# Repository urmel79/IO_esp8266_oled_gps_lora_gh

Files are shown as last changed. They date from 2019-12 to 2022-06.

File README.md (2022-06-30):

# LoRa and LoRaWAN testing bench with GPS tracking

Last changed on June 30, 2022.

## Table of contents

<!--
@HINT:
auto-generate the TOC with the command line tool 'gh-md-toc' (https://github.com/ekalinin/github-markdown-toc) with following syntax:
$ cat README.md | ./tools/github-markdown-toc/gh-md-toc - > toc.md
-->

* [Introduction](#introduction)
  * [Aim of the project](#aim-of-the-project)
  * [Requirements to the testing bench](#requirements-to-the-testing-bench)
* [A brief overview of LoRa topologies](#a-brief-overview-of-lora-topologies)
* [LoRa or LoRaWAN? - The difference is 1 GPIO pin of the ESP](#lora-or-lorawan---the-difference-is-1-gpio-pin-of-the-esp)
* [Node-RED Flows](#node-red-flows)
* [Display GPS tracks on OSM worldmap](#display-gps-tracks-on-osm-worldmap)
* [Storing the transmitted data: SQLite database layout](#storing-the-transmitted-data-sqlite-database-layout)
* [Visual impressions of my experimental breadboard setup](#visual-impressions-of-my-experimental-breadboard-setup)
* [Bill of materials (BOM)](#bill-of-materials-bom)
* [Breadboard layout and schematics (version with ESP8266)](#breadboard-layout-and-schematics-version-with-esp8266)
* [Breadboard layout and schematics (version with ESP32)](#breadboard-layout-and-schematics-version-with-esp32)
* [Troubleshooting](#troubleshooting)
  * [Writing serial output with timestamps to a logfile](#writing-serial-output-with-timestamps-to-a-logfile)
    * [Method 1: Use minicom](#method-1-use-minicom)
    * [Method 2: Use command line tools](#method-2-use-command-line-tools)
  * [I²C: fighting strange pixel errors on OLED display](#ic-fighting-strange-pixel-errors-on-oled-display)
    * [Observation](#observation)
    * [Thesis 1: EMC issues with the LoRa radio module](#thesis-1-emc-issues-with-the-lora-radio-module)
    * [Thesis 2: Power supply of the MCU is to weak](#thesis-2-power-supply-of-the-mcu-is-to-weak)
    * [Thesis 3: I²C signals at SDA and SCL line are disturbed](#thesis-3-ic-signals-at-sda-and-scl-line-are-disturbed)
* [License](#license)

# Introduction

## Aim of the project

The aim of this project is to build a test environment based on ESP8266 or ESP32 for [LoRa](https://en.wikipedia.org/wiki/LoRa) and LoRaWAN as [LPWAN](https://en.wikipedia.org/wiki/LPWAN) long-range radio network.

## Requirements to the testing bench

For this purpose, two identical test modules were each equipped with a LoRa transceiver, a GPS module and an OLED display for displaying the current data.

Both test modules were initially prototypically built on breadboards. Power is supplied via the microUSB port of the ESP8266 NodeMCU (respectively NodeMCU ESP-32S) and optionally connected to the USB port of the development computer. This allows debugging via the serial interface and the serial monitor at the same time.

Alternatively, a LiPo power bank can also be used for both test modules, making them mobile for upcoming range tests.

At the moment, watertight food storage boxes are used as provisional and outdoor-suitable housings.

Firmware updates can be submitted via USB-to-serial interface or by using the *Over-The-Air (OTA)* update functionality to take advantage of maximum mobility :) In my opinion this is an essential feature for IoT applications! For an introduction to this technique start here: [Over-the-air programming](https://en.wikipedia.org/wiki/Over-the-air_programming) or there: [ESP8266 OTA Updates with Arduino IDE | Over the Air](https://randomnerdtutorials.com/esp8266-ota-updates-with-arduino-ide-over-the-air/).

GPS coordinates are transferred via MQTT to a Raspberry-based Node-RED-Server. On this server there is a dedicated flow what cares for
- the displaying on the OpenStreetMap widget (install *'node-red-contrib-web-worldmap'* package) and
- the storage of the GPS coordinates (smoothed by floating average) in a SQLite database (install *'node-red-node-sqlite'* package).

# A brief overview of LoRa topologies

LoRa is usable in an **Point to Point communication** like this:

<!-- @TODO: insert image of LoRa p2p -->
(image will follow soon)

Furthermore, it can be used in an full blown LoRa network on the basis of **LoRaWAN** like this:

<!-- @TODO: insert image of LoRaWAN network -->
(image will follow soon)

# LoRa or LoRaWAN? - The difference is 1 GPIO pin of the ESP

For the application of a [TTN](https://www.thethingsnetwork.org/docs/) based LoRaWAN network 1(!) additional GPIO pin of the ESP mcu to the LoRa transceiver module is required. Unfortunately, this pin of the ESP8266 is not available because all others are already occupied by the other peripherals and communication channels (e. g. *UART* to the gps sensor, *I2C* to the OLED display and *SPI* to the LoRa transceiver module itself).

Because of this dilemma the whole project had to be migrated for the use of ESP32 with its significantly more GPIO pins. It was a hard piece of work since there are many differences in the Arduino API especially in the wifi handling. So there are many `#defines` in the source for choosing the right mcu platform and software modules.

# Node-RED Flows

Here you can see the Node-RED Flow for displaying the GPS coordinates on the OpenStreetMap and for storaging in an SQLite database for 2 ESP nodes:

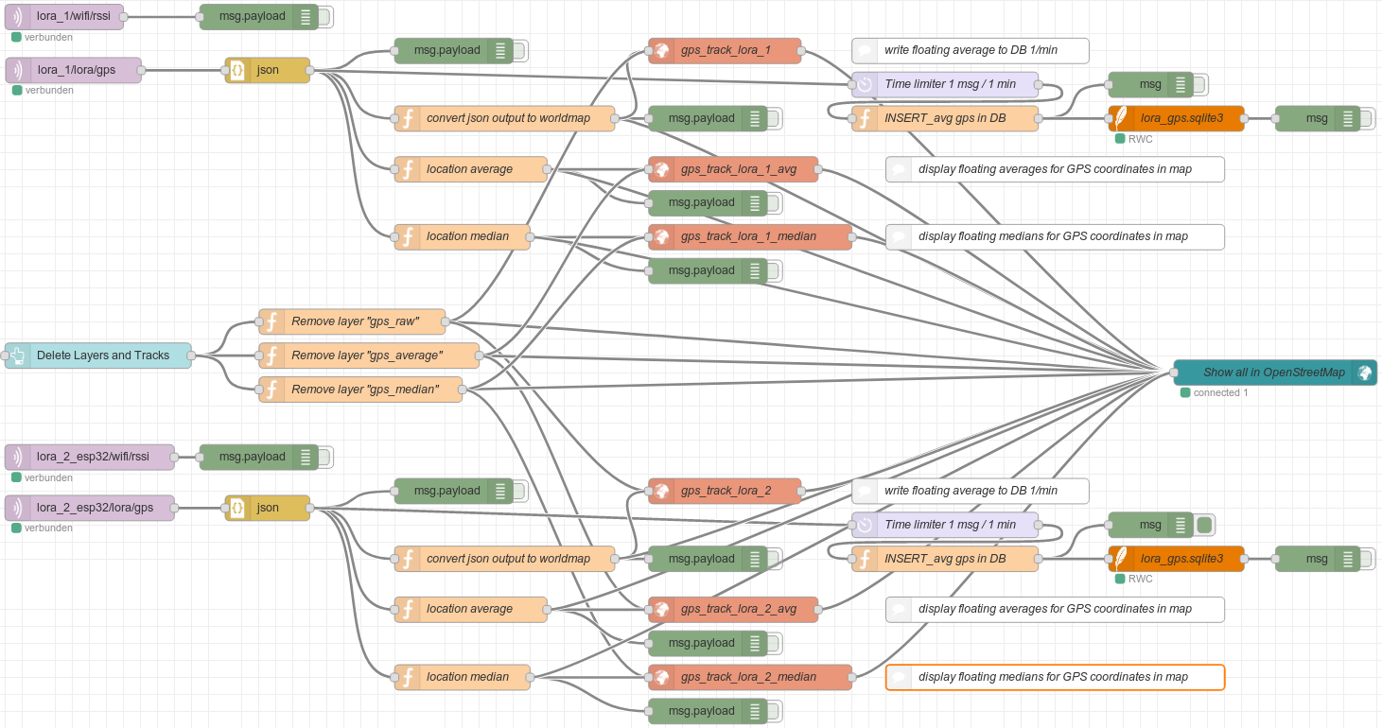
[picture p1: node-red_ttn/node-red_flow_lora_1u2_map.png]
Node-RED Flow LoRa Nodes 1 and 2 and GPS mapping


There is my Node-RED Flow ready to import it to your own Node-RED installation [lora_1u2_map.json](./node-red_ttn/lora_1u2_map.json). To use it, you have to additionally install following Node-RED packages:

- `node-red-dashboard`
- `node-red-contrib-web-worldmap`
- `node-red-node-sqlite`

# Display GPS tracks on OSM worldmap

The experimental breadboard setup (including the gps sensor) is located on the outside windowsill of my office with a view to the southeast. This is a screenshot of the OSM worldmap and the gps tracks recorded over some time:

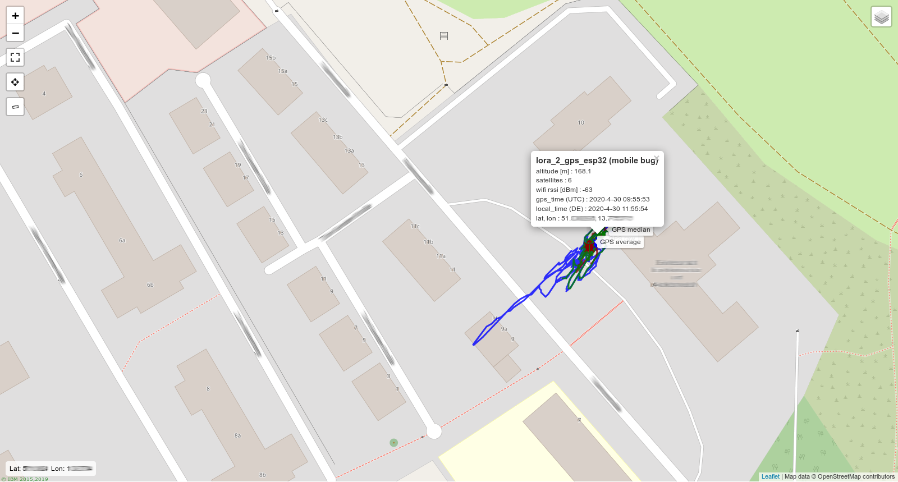
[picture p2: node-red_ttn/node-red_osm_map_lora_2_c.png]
OSM worldmap with LoRa 1


The colors of the gps tracks have the following meaning:

- blue: *raw* positioning data from gps sensor
- red: smoothed data by *running average*
- green: smoothed data by *running median*

# Storing the transmitted data: SQLite database layout

Here is a screenshot of *phpLiteAdmin* to show my SQLite database layout for storing the GPS coordinates:

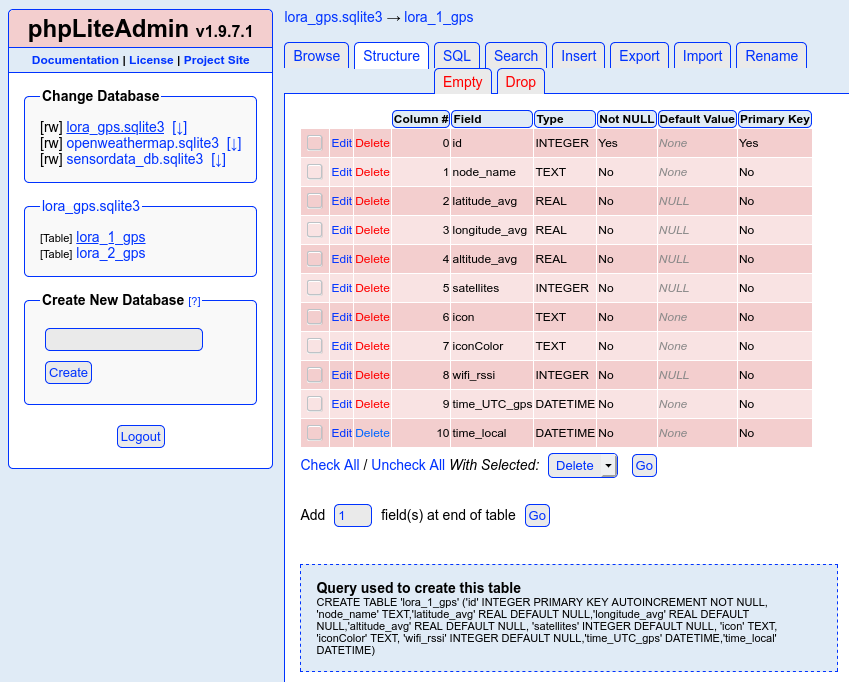
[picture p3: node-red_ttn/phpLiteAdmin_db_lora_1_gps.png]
SQLite database layout


# Visual impressions of my experimental breadboard setup

Here you can see one of two test modules build on breadboard:

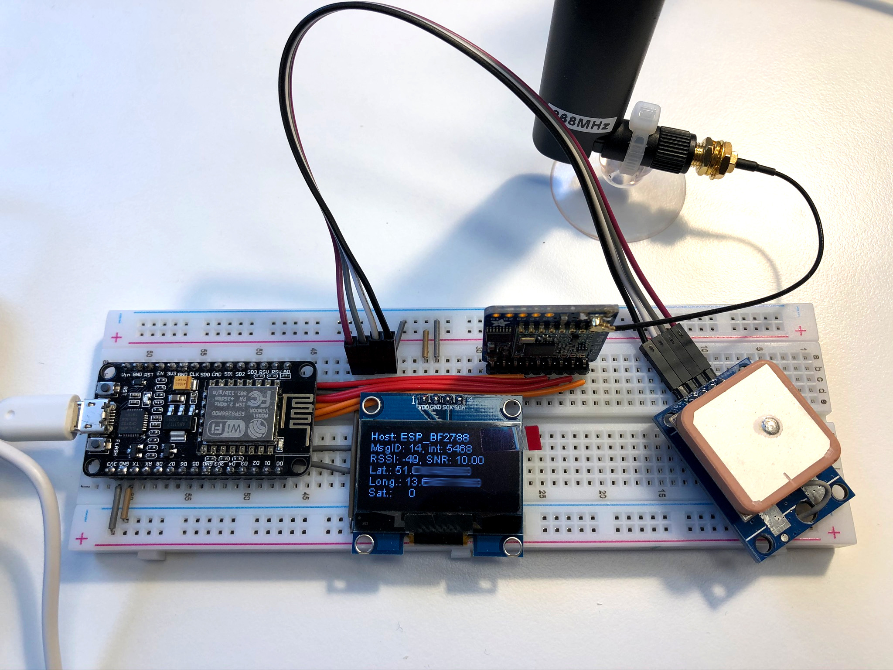
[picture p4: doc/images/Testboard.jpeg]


In this picture you can see the other test module on top of the provisional and outdoor-suitable housing (watertight food storage box):

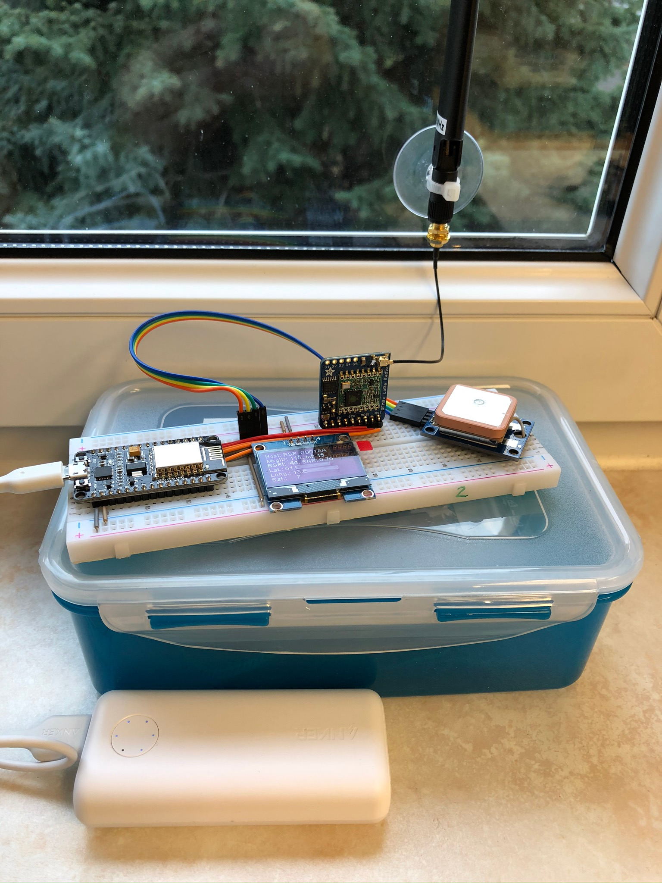
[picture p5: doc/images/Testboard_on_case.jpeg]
Breadboard Layout and case


# Bill of materials (BOM)

Following parts I have used in this project (every component you will need twice of course):

- **NodeMCU v2 (ESP8266)** or **NodeMCU ESP-32S**
- OLED I2C display, 128 x 64 Pixel, 1.3 Zoll (SSH1106 chip)
- GPS module u-blox Neo-6M (GY-GPS6MV2 chip)
- LoRa transceiver Adafruit RFM9x LoRa Radio (RFM95W chip, 868 MHz)
- LoRa antenna (868 MHz), 3 dBi omnidirectional
- u.FL/IPEX to SMA connector (so called 'pigtail')
- USB cable with micro USB plug
- breadboard full+ (830 holes)
- wire jumpers
- LiPo battery pack

# Breadboard layout and schematics (version with ESP8266)

With *Fritzing* (https://fritzing.org) I have created following breadboard layout:

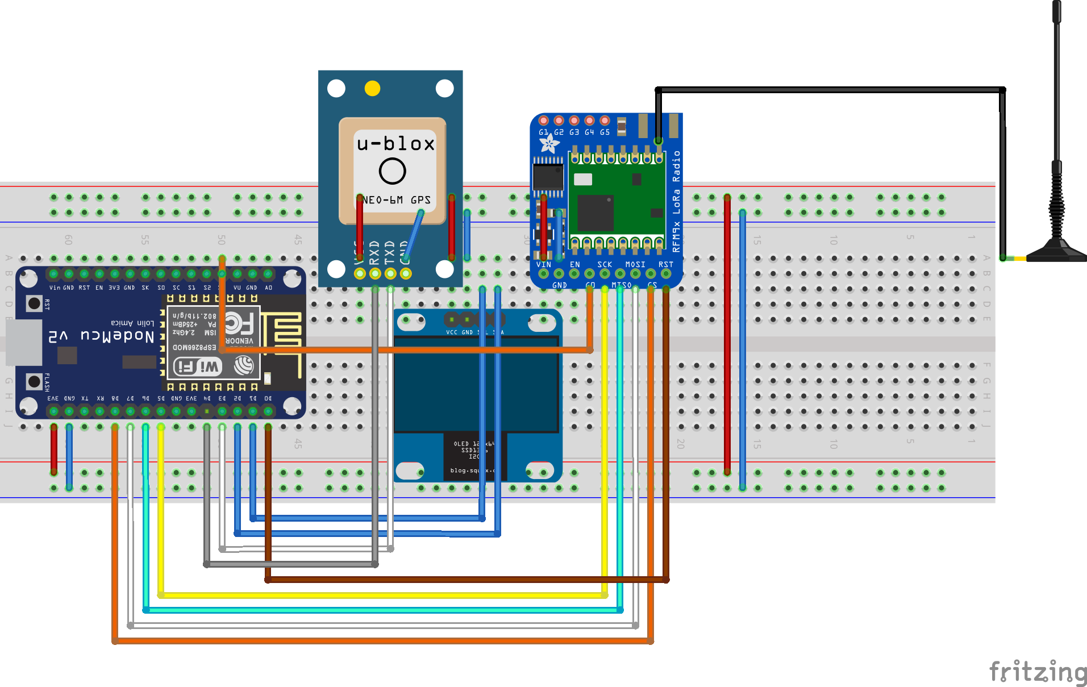
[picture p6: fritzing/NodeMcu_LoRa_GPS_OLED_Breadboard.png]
Breadboard Layout


The schematics looks like this:

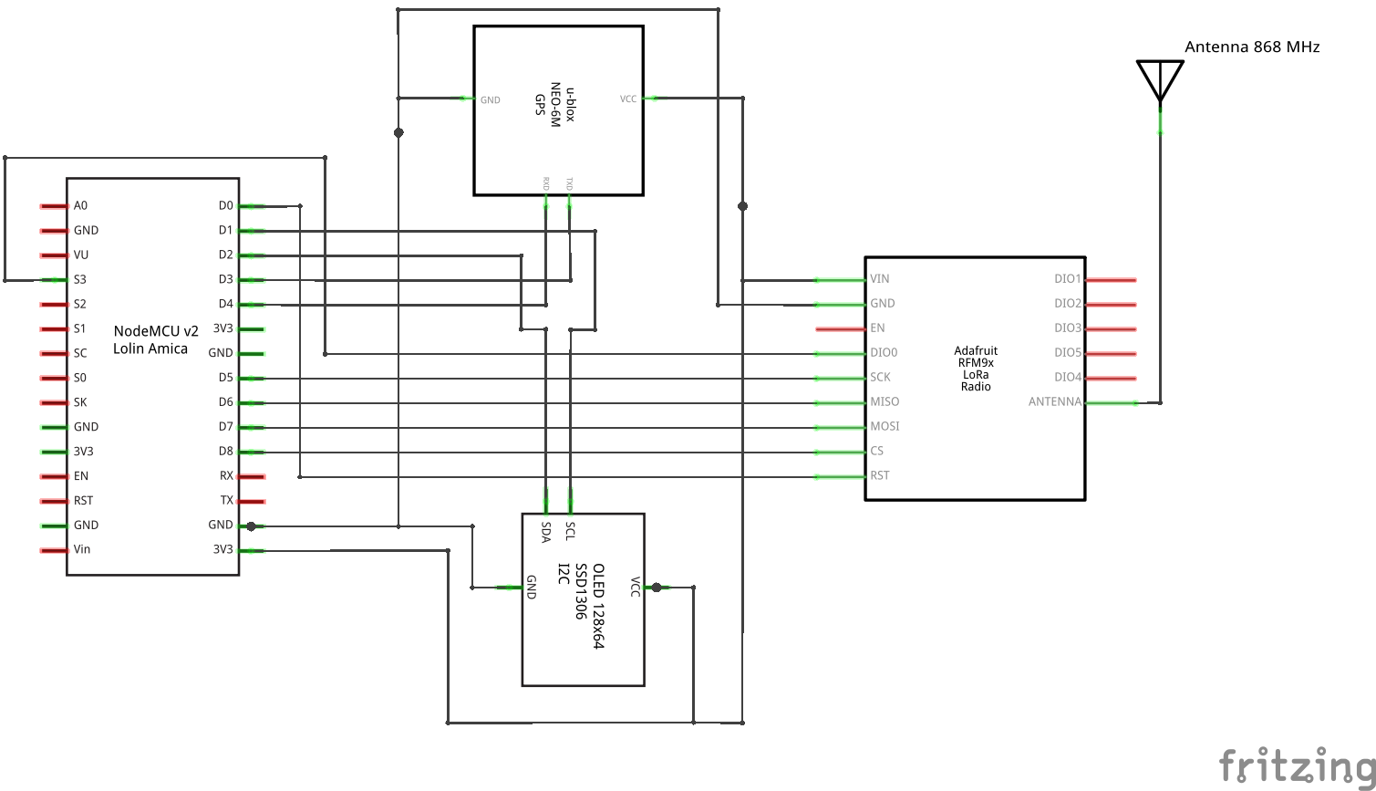
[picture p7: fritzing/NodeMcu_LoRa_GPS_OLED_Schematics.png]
Schematics


# Breadboard layout and schematics (version with ESP32)

With *Fritzing* (https://fritzing.org) I have created following breadboard layout:

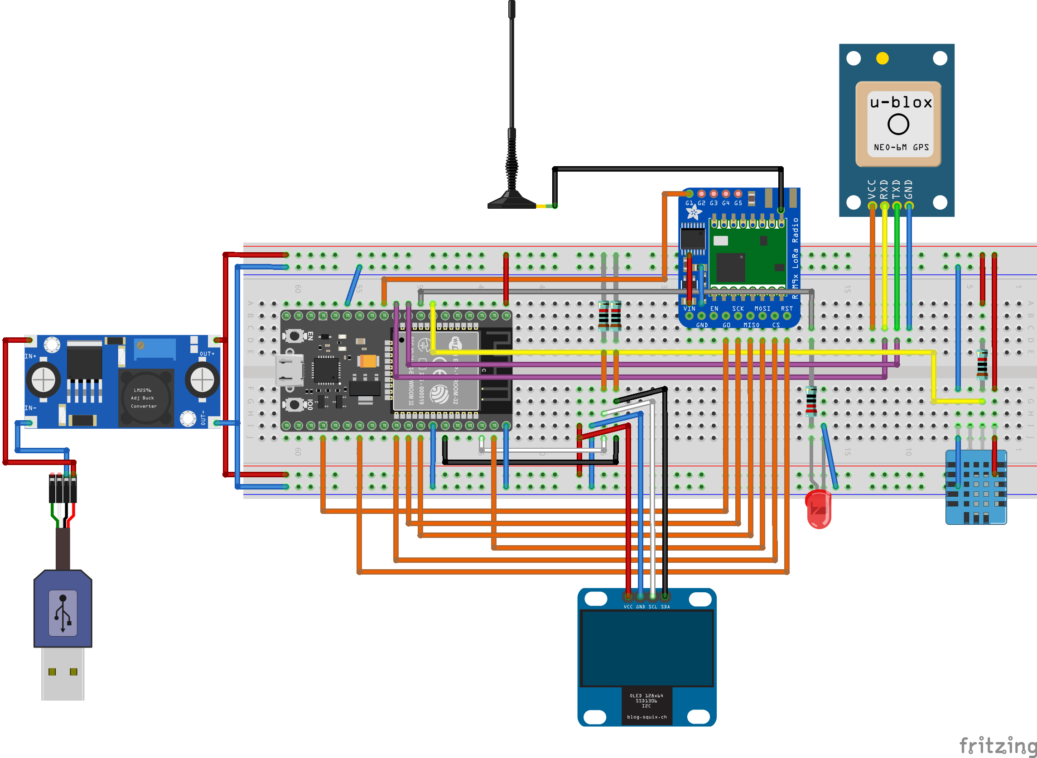
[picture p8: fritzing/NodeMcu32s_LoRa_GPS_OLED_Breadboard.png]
Breadboard Layout


The schematics looks like this:

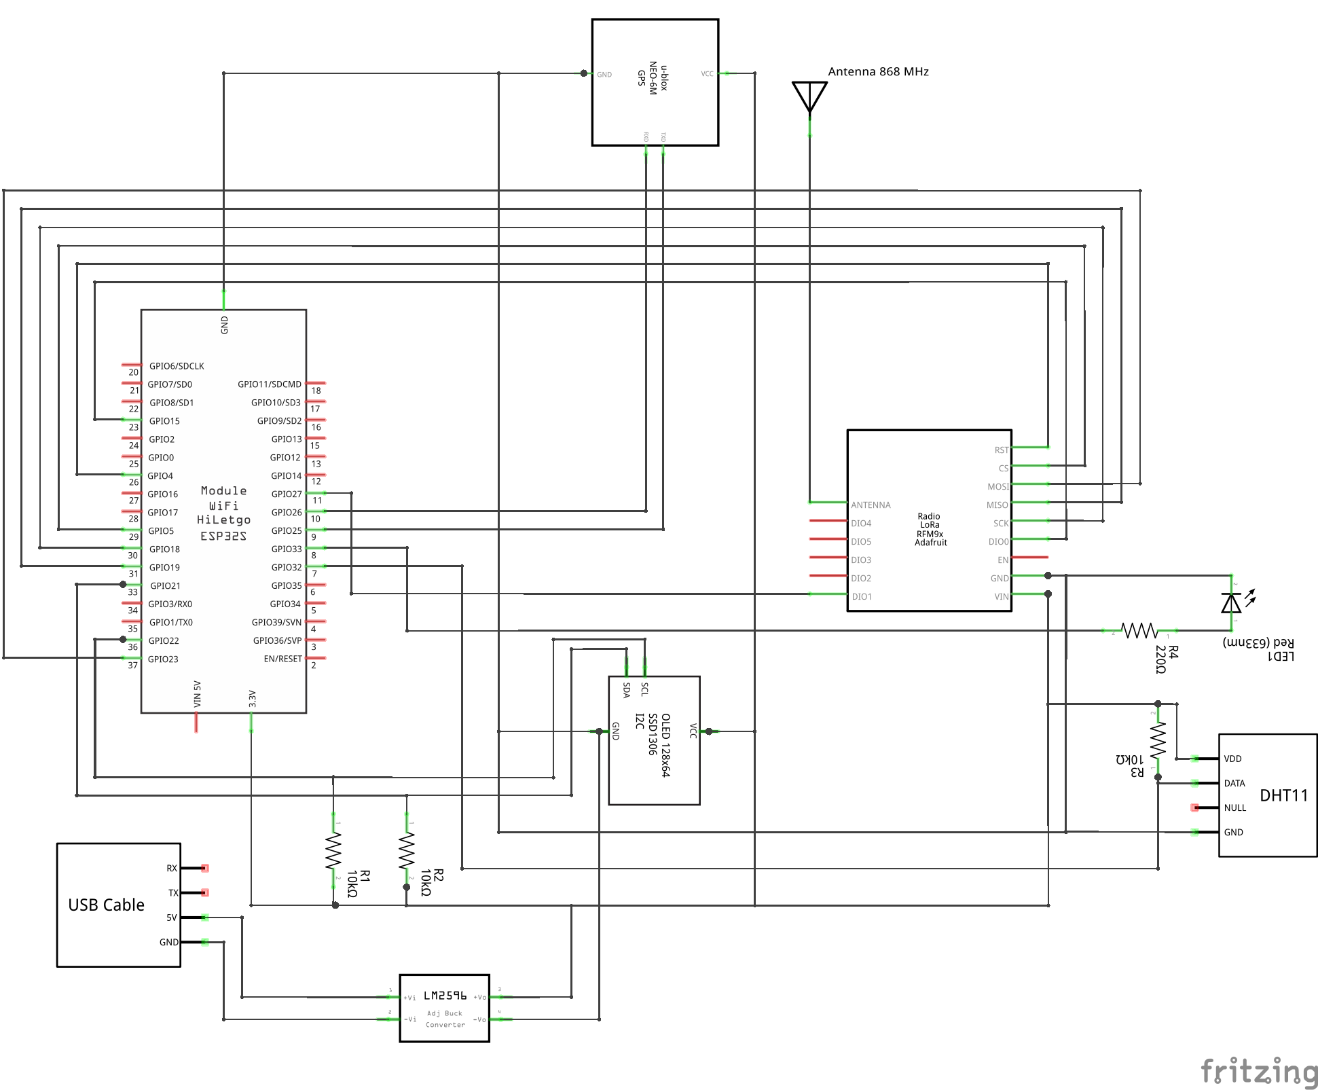
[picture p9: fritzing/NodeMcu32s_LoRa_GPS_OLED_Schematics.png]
Schematics


<!--## Software libraries and documentation

Go to the source code: I have supplied it with many comments for explanation.-->

# Troubleshooting

In this section I will describe some typical hardware or software problems that I have struggled with for several days.

(to be continued)

## Writing serial output with timestamps to a logfile

Connect the ESP8266 / ESP32 via a microUSB cable directly to a Linux computer or a Raspberry Pi.

### Method 1: Use `minicom`

Start `minicom` and configure the serial connection via `C-a o`. Especially the path to the serial device (e. g. `/dev/ttyUSB0`), the correct baud rate (115200 baud) and the stop and parity bits (8N1) have to be set.

Activate timestamps via `C-a n`. Do that several times and cycle through the timestamps modes: 'no timestamps', 'simple timestamps' and 'advanced timestamps' (with milliseconds). I use the latter mode, because the serial output with 115200 baud is really fast. See the screenshot below.

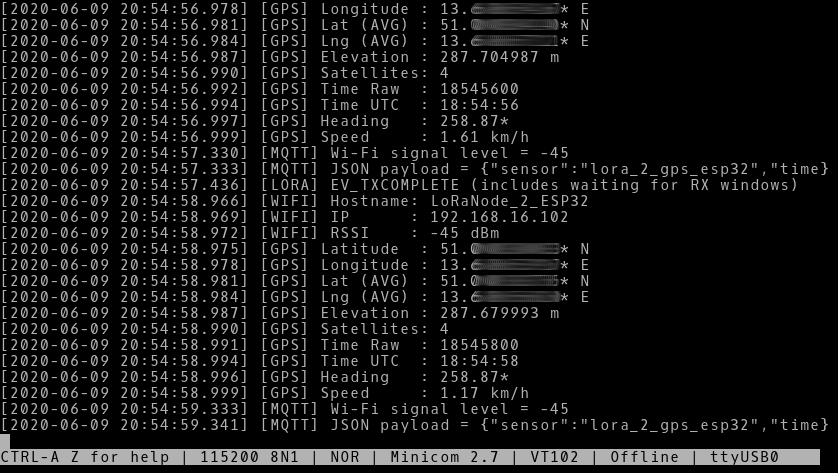
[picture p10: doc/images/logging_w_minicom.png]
Screenshot of minicom with activated timestamps


Activate the logging function in `minicom` via `C-a l`. In the dialog box you have to set your desired file name.

### Method 2: Use command line tools

Build a pipeline with several command line tools. For getting timestamps I use the `ts` command - the package `moreutils` has to be installed first (`# apt install moreutils`).

**Prerequisite:** The serial device has to be opened first with the correct settings via another serial tool, like `minicom`.

This is the complete command pipeline:

`$ ts '[%Y-%m-%d %H:%M:%.S]' < /dev/ttyUSB0 | tee -a $(date +%Y-%m-%d)_esp32.log`

Here is the screenshot showing this method:

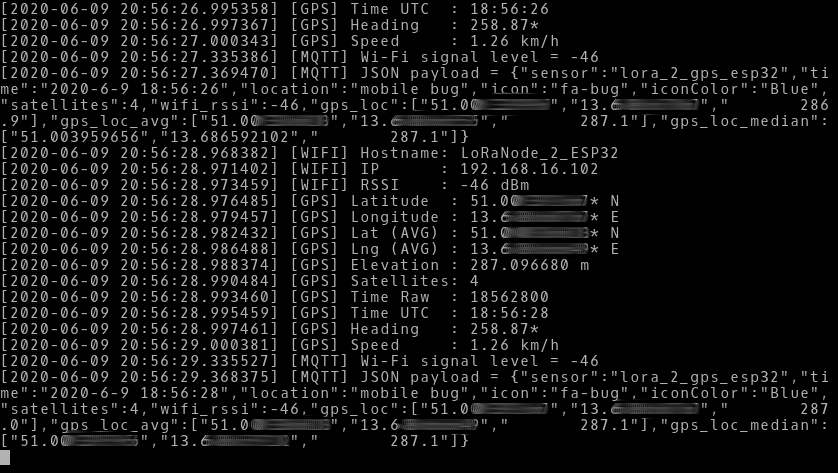
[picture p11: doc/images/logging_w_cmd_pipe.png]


The advantage of piping the `tee` command is, that you can watch the serial output while the logging is done in the background. The option `-a` means, that the given file is appended and not overwritten.

## I²C: fighting strange pixel errors on OLED display

### Observation

After some time there are random pixel errors on the OLED display. It can also happen that the display turns almost completely white and nothing is readable anymore.

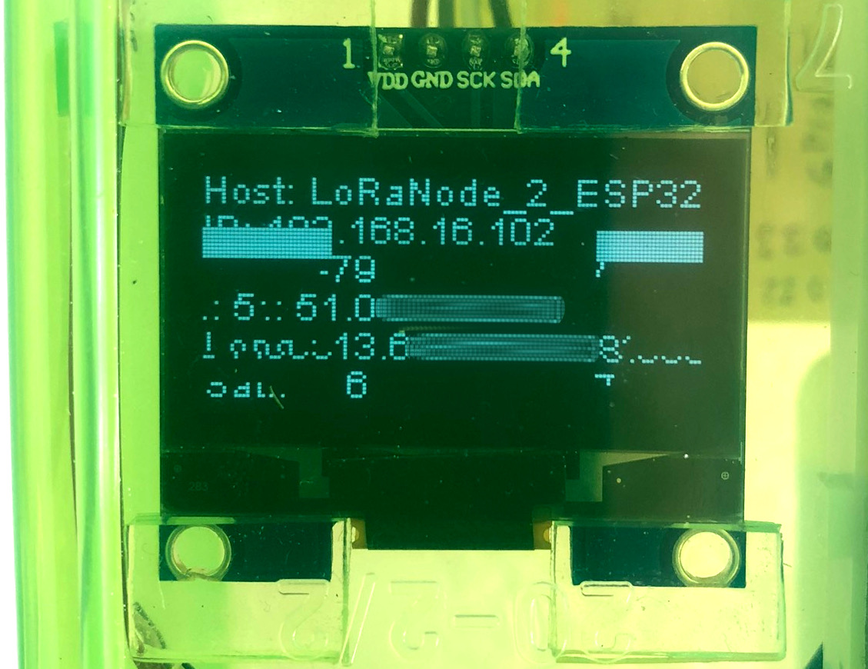
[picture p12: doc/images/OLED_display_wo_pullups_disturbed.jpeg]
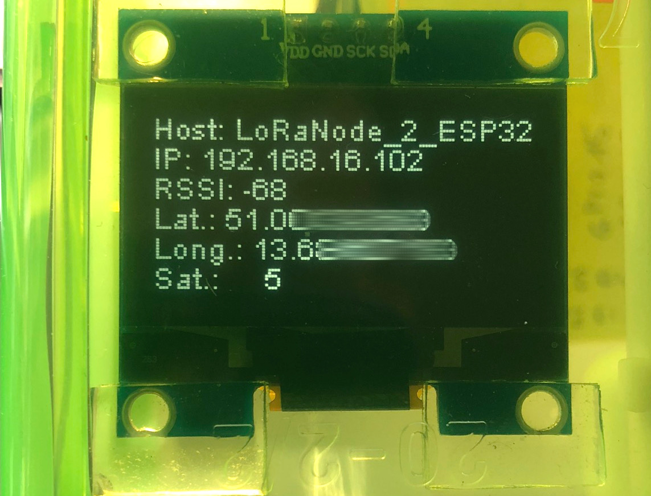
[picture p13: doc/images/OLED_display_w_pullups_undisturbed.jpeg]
|  |   |
| :---- | :---- |
| Strange pixel errors on disturbed display | Undisturbed display |

Hint: I blurred the GPS positions for data protection reasons on both images.

### Thesis 1: EMC issues with the LoRa radio module

**Approach:**  
Shielding with a grounded copper shield (self-adhesive copper foil) and soldered wires to ground.

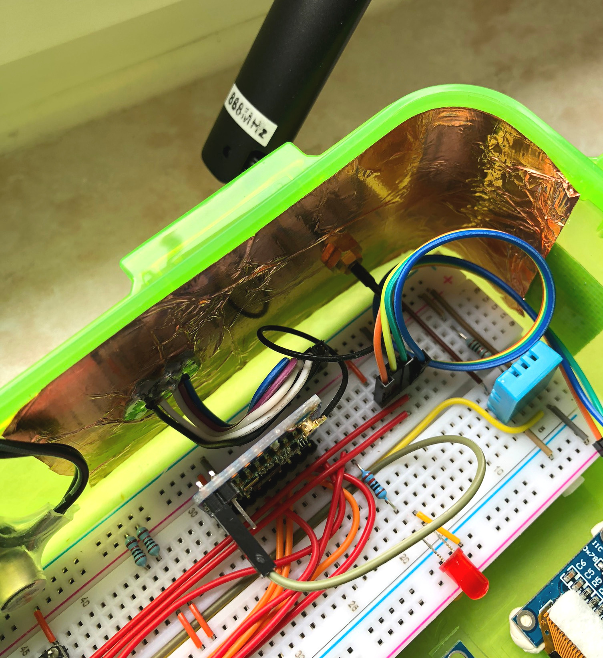
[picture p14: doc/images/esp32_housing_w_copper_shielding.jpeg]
Shielding with a grounded copper shield


**Results:**  
- LoRa signal strength (RSSI value in dB) decreased significantly
- display errors still appear after a while

### Thesis 2: Power supply of the MCU is to weak

**Approach:**  

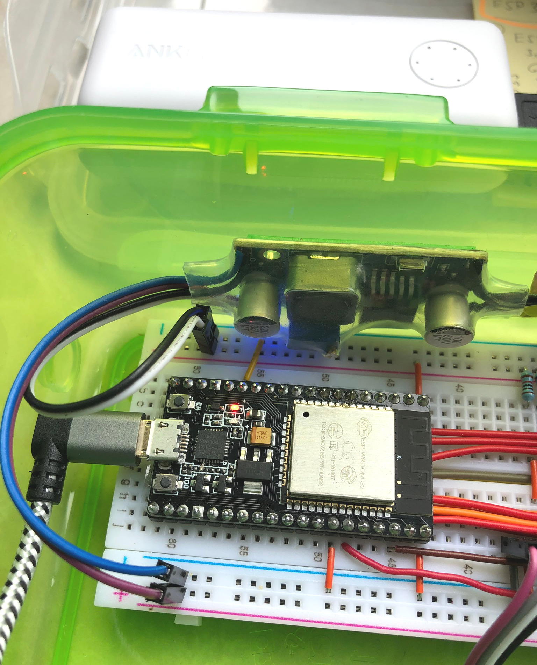
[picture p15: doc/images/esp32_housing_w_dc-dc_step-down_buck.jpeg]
External power supply via adjustable DC-DC step-down converter


**Results:**  

### Thesis 3: I²C signals at SDA and SCL line are disturbed

Because the OLED display is connected to the I²C bus, I used my storage oscilloscope to examine the signal quality on both the clock (SCL) and the data line (SDA). It turned out that both signals were very disturbed and that the signal edges were not sufficiently good.

**Approach:**  

**Results:**  

Wikipedia:  
- [I²C | Physical layer](https://en.wikipedia.org/wiki/I%C2%B2C#Physical_layer)
- [Pull-up resistor](https://en.wikipedia.org/wiki/Pull-up_resistor)

Forum:  
- [OLED mini-display for ESP32](https://forum.micropython.org/viewtopic.php?t=3764)

# Migrate to MySQL, phpMyAdmin and Grafana

Data  from the nodes are stored in SQLite databases until now. The graphical admin gui is *phpLiteAdmin*.

For advanced exploring the data *Grafana* is a very useful tool. Unfortunately it does not support SQLite databases as data sources. So the challenging task is to install MySQL, PHP7, Grafana and for administration of the MySQL databases *phpMyAdmin*. Then the massive data of the SQLite databases collected in the last half year have to be converted to the MySQL compatible format.

To install the pre-requisites I had done the following on my Raspi with Raspbian GNU/Linux 9.13 (stretch):

Sources:
- [Raspberry PI: Einrichten eines MySQL Datenbankservers (+phpMyAdmin)](https://draeger-it.blog/raspberry-pi-einrichten-eines-mysql-datenbankservers/)
- [Setup a Raspberry Pi MYSQL Database](https://pimylifeup.com/raspberry-pi-mysql/)*
- [How to Install PHPMyAdmin on the Raspberry Pi](https://pimylifeup.com/raspberry-pi-phpmyadmin/)*

```
# apt update
# apt upgrade

# apt install mysql-server
//# apt install libapache2-mod-auth-mysql phpmyadmin
# apt install phpmyadmin

# nano /etc/apache2/apache2.conf
# service apache2 restart
```

phpMyAdmin is now reachable here: [http://192.168.16.184/phpmyadmin/](http://192.168.16.184/phpmyadmin/)

```
# nano /etc/php5/apache2/php.ini
# nano /etc/php/7.0/apache2/php.ini
# cat /etc/php/7.0/apache2/php.ini | grep -i extension=mysql
# mysql -u root -p

# service apache2 restart
# wget -q -O - https://packages.grafana.com/gpg.key | sudo apt-key add -
# echo "deb https://packages.grafana.com/oss/deb stable main" | sudo tee -a /etc/apt/sources.list.d/grafana.list
# apt update
# apt install grafana
# systemctl status grafana-server
# systemctl start grafana-server

```

## Convert SQLite databases to MySQL format

Unfortunately the data formats and SQL syntaxes are **not** compatible between SQLite and MySQL databases! So you have to convert the database dump files from one format to the other. Especially if there are plenty of datasets the use of a tool is strongly recommended. I used the python tool [sqlite3-to-mysql](https://github.com/techouse/sqlite3-to-mysql) here. First you have to install it via `pip install sqlite3-to-mysql`.

The tool will convert the SQLite data and stream it directly to the MySQL database - so it will be easier if you do it directly on the hosting Raspberry Pi (and slower of course). The name of the existing database in MySQL is here `lora_gps`.

```
$ sqlite3mysql -c 500 -f lora_gps.sqlite3 -d lora_gps -u <mysql user> -p '<password of mysql user>'
```

## Install Grafana

The installation process is very straight forward and described here: [Install Grafana](https://grafana.com/tutorials/install-grafana-on-raspberry-pi/#3).

# License

This project is licensed under the terms of "GNU General Public License v3.0". For details see [LICENSE](LICENSE).

<!--  -->

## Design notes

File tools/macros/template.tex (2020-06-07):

\usepackage{graphicx}
\usepackage[utf8]{inputenc}     %damit man Sonderzeichen wie ä, ö, ü und ß direkt eingeben kann
\usepackage[T1]{fontenc}   % Ausgabezeichensatzkodierung; T1
\usepackage[german]{varioref}
\usepackage[ngerman]{babel}

% -----------------------
% Using abstracts
\usepackage{abstract}

% -----------------------
% Using fancy headers and footers
% \usepackage{fancyhdr}
% \pagestyle{fancy}
% \fancyhead[CO,CE]{$header$}
% \fancyfoot[CO,CE]{$footer$}
% \fancyfoot[LE,RO]{\thepage}

% \textwidth 15cm
% \topmargin -0.5cm
% \leftmargin 0.5cm
% \textheight 23cm

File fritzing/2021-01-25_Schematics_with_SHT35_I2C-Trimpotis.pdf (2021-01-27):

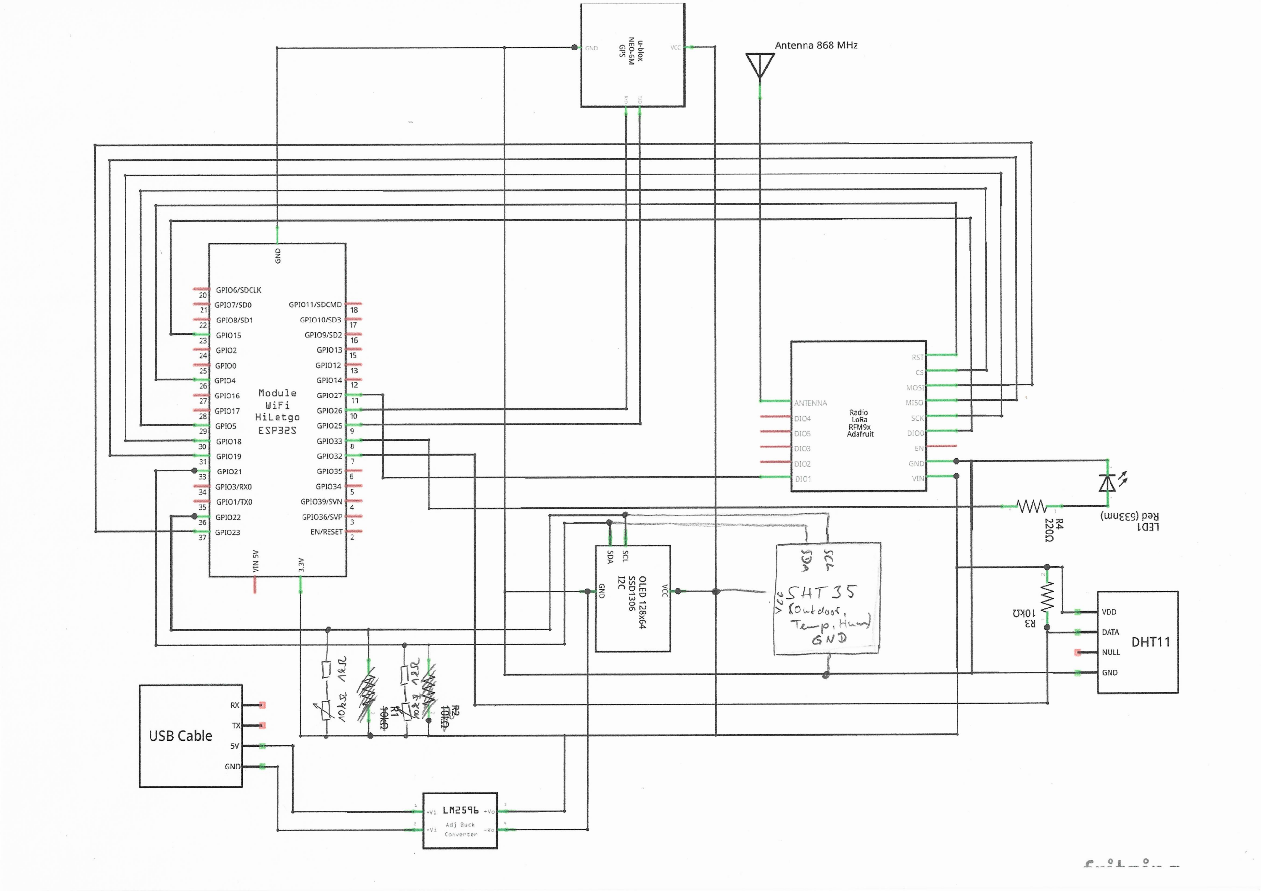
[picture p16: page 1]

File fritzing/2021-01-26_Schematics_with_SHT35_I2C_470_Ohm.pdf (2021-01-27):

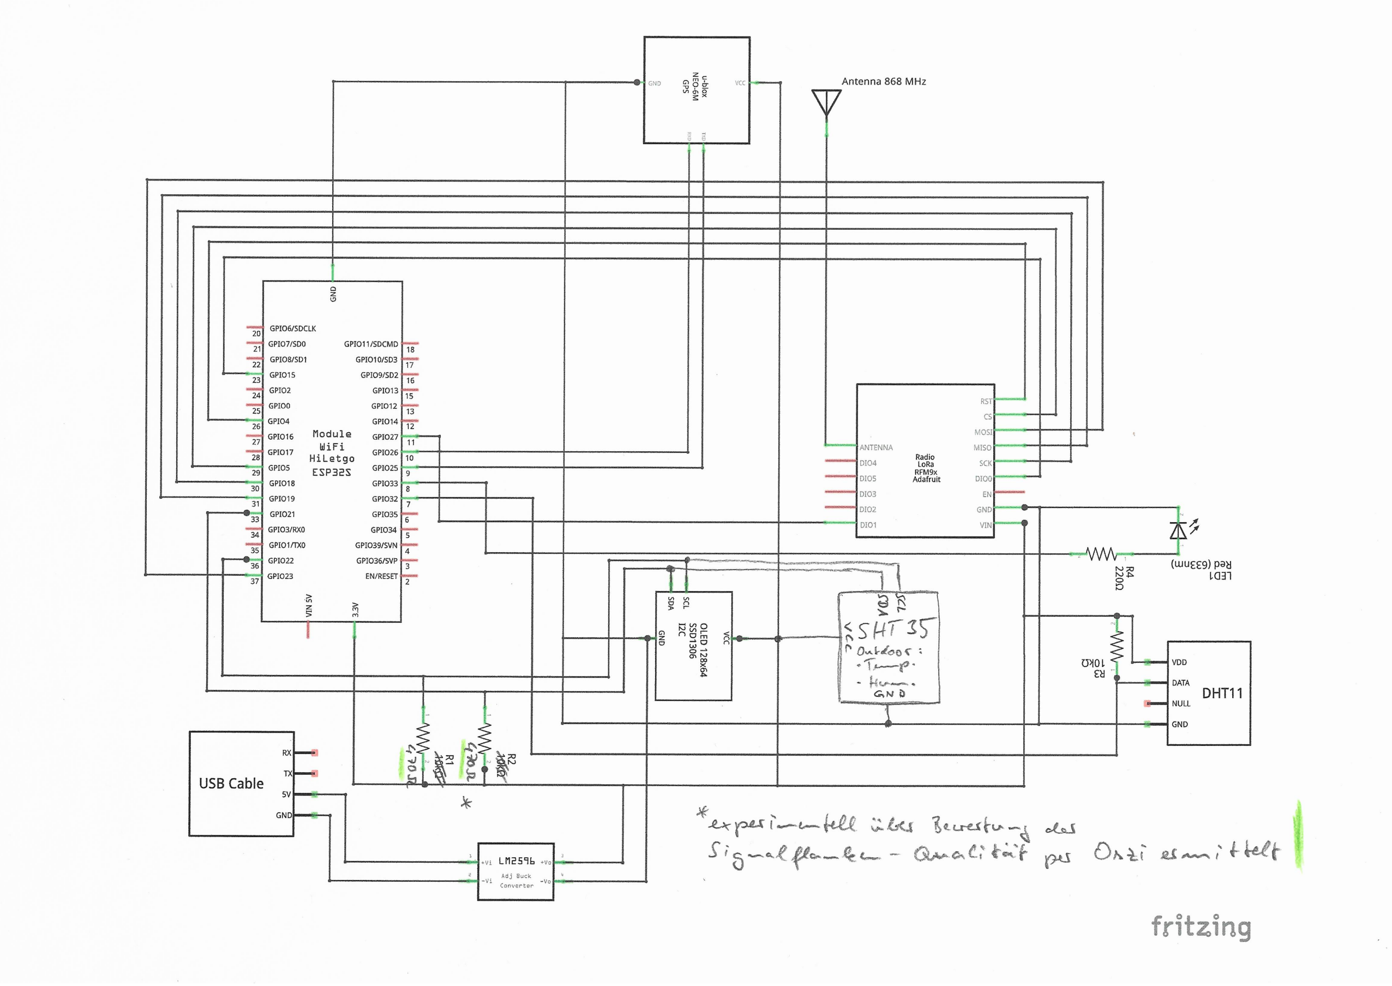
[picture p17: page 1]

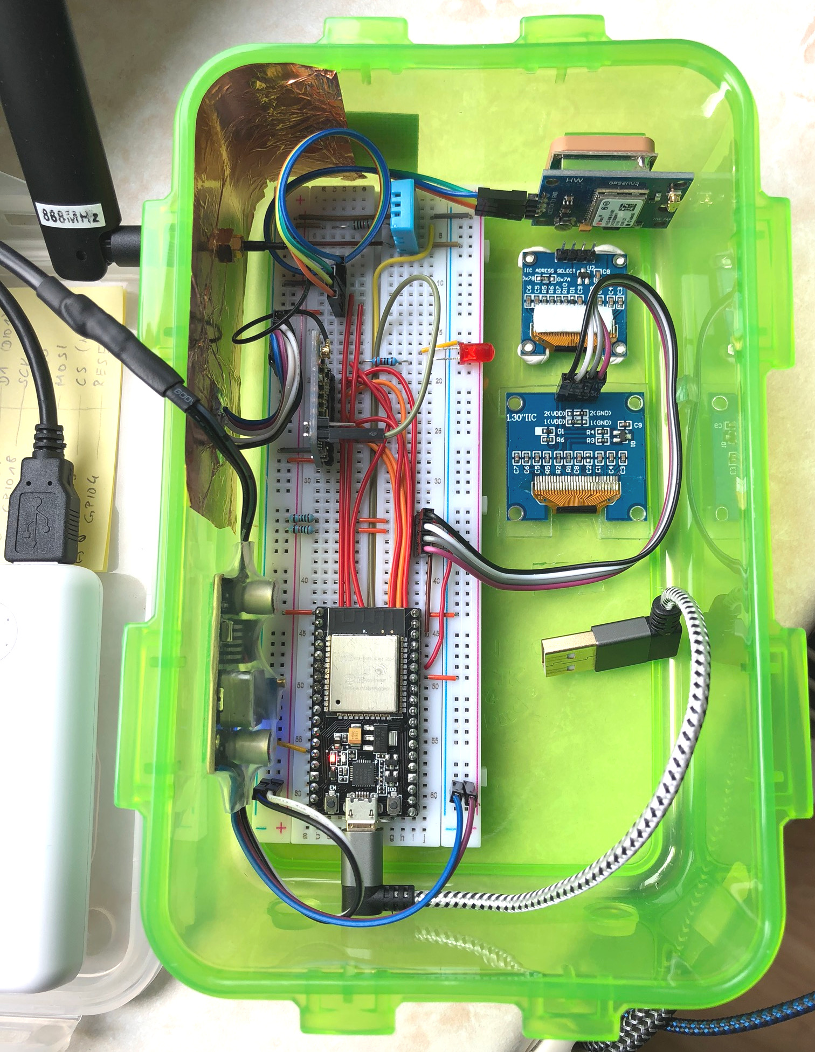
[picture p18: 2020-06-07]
doc/images/esp32_housing_inside_view.jpeg

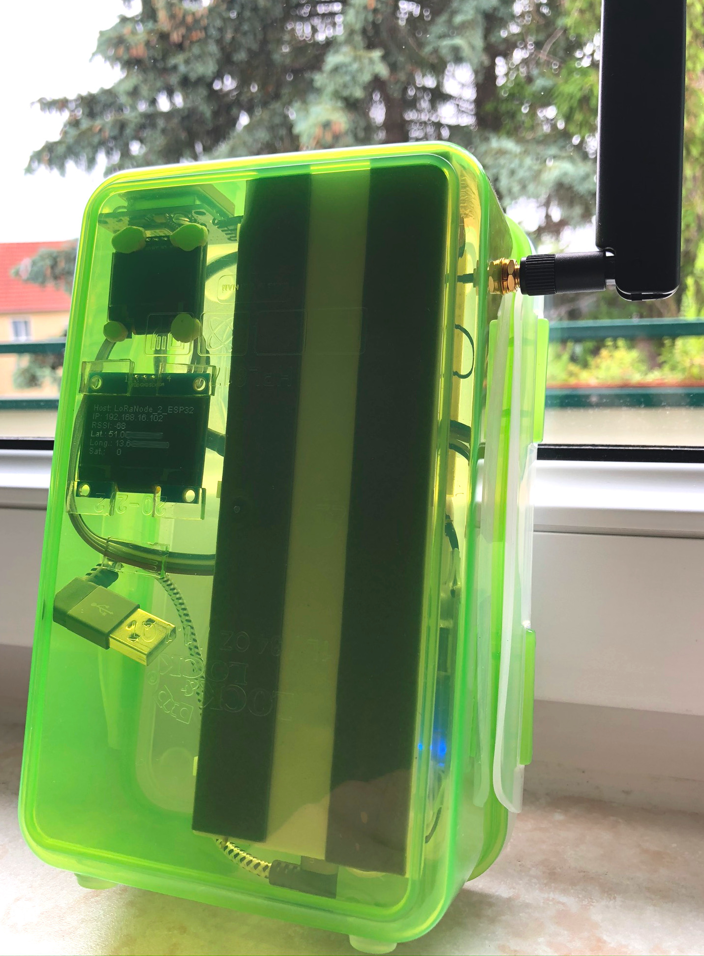
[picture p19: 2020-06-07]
doc/images/esp32_housing_outside_view.jpeg

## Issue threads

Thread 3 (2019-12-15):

sporadic system crashes

urmel79, 2019-12-15:
- sporadic system crashes especially when WiFi is not connected
- OTA updates do not work and also lead to system crash and reboot

urmel79, 2019-12-15:
[bug] external interrupts conflict with WiFi connection attempts or OTA updates and lead to sporadic crashes!
[fix (workaround)] disable external GPIO interrupts temporarily

```c++
void connectToWifi() {
  Serial.println("Connecting to Wi-Fi...");
  WiFi.mode(WIFI_STA);  // client mode

  // [bug] external interrupts conflict with wifi connection attempts and
  // ota updates and lead to sporadic crashes!
  // [fix (workaround)] disable external interrupts temporarily
  // reference https://www.mikrocontroller.net/topic/460256#5573848
  ETS_GPIO_INTR_DISABLE();
  WiFi.begin(WIFI_SSID, WIFI_PASSWORD);

  // enable external interrupts again
  ETS_GPIO_INTR_ENABLE();
}
```

Closed 2019-12-15.

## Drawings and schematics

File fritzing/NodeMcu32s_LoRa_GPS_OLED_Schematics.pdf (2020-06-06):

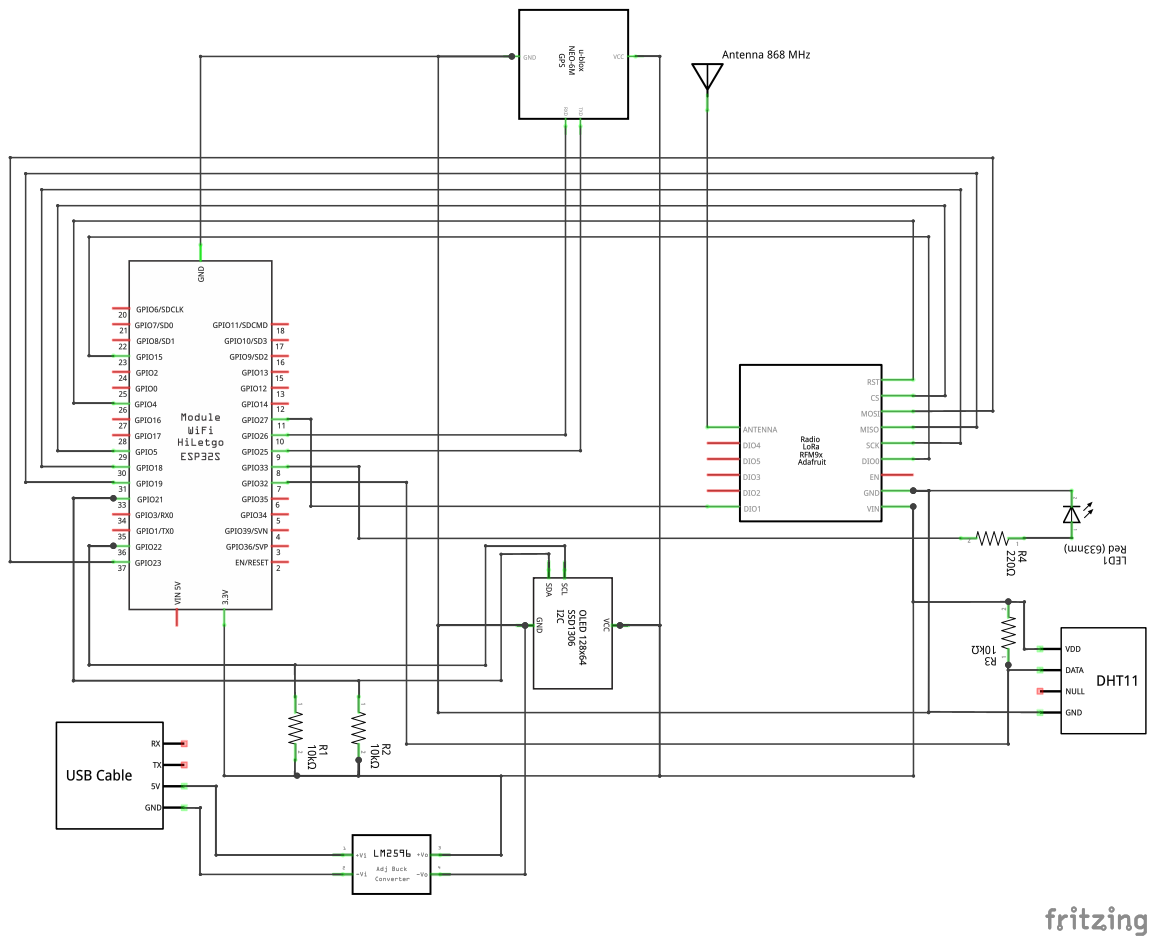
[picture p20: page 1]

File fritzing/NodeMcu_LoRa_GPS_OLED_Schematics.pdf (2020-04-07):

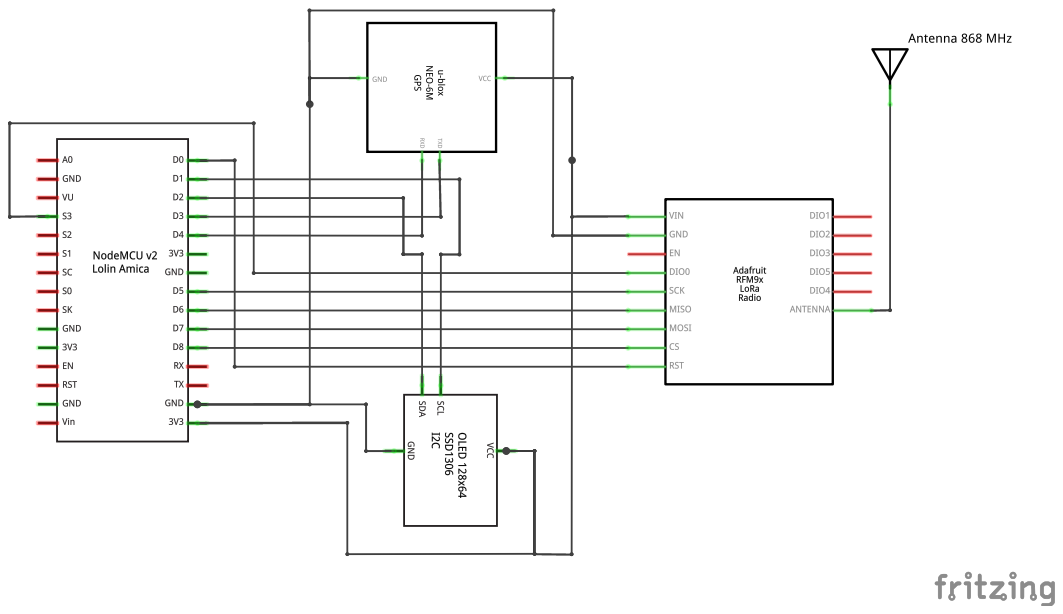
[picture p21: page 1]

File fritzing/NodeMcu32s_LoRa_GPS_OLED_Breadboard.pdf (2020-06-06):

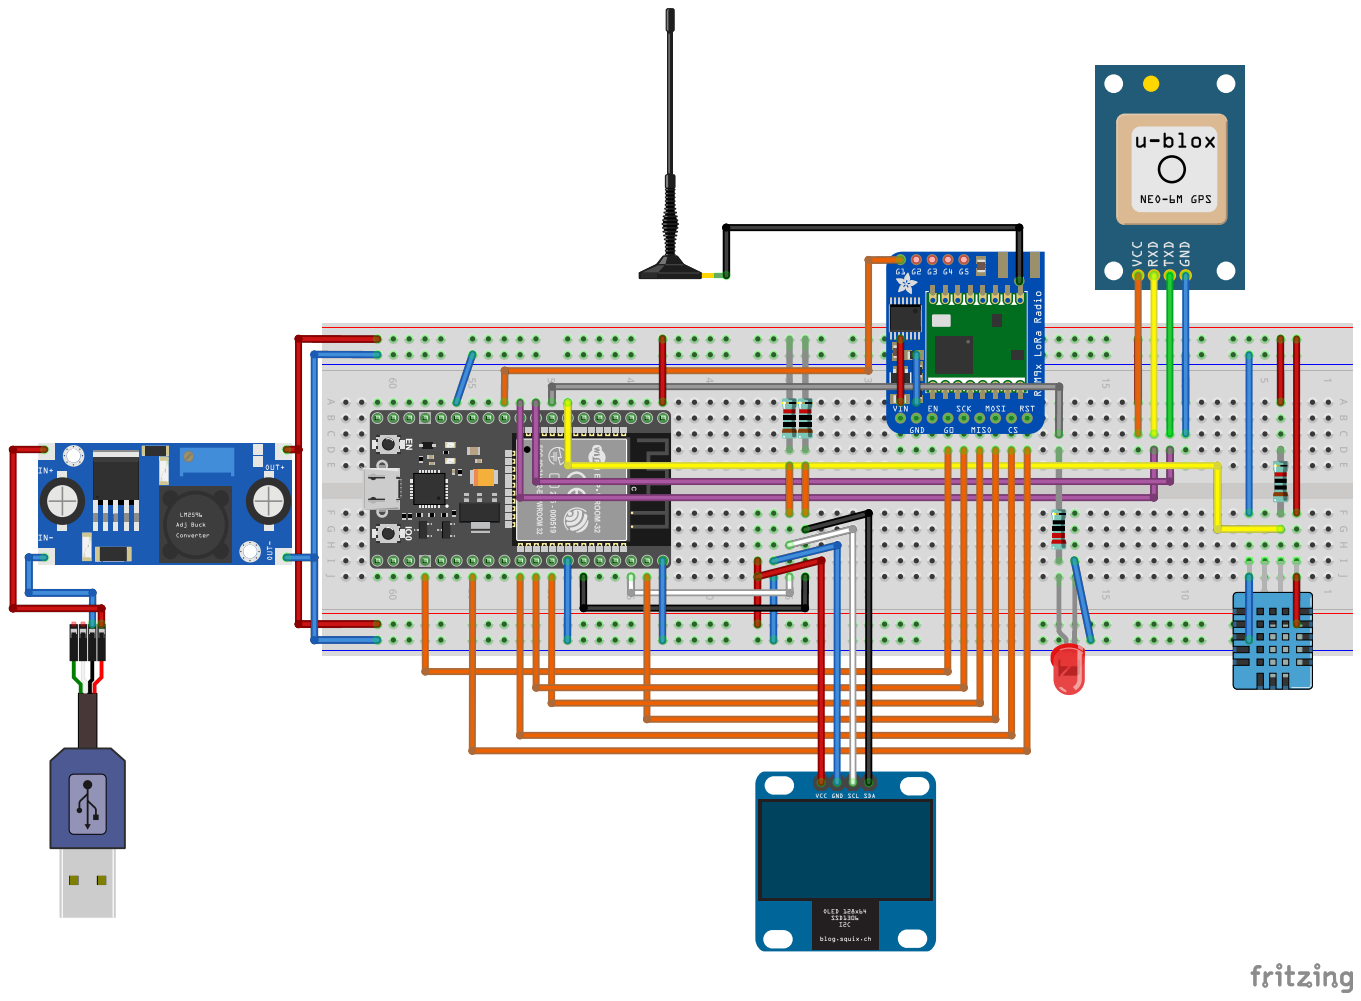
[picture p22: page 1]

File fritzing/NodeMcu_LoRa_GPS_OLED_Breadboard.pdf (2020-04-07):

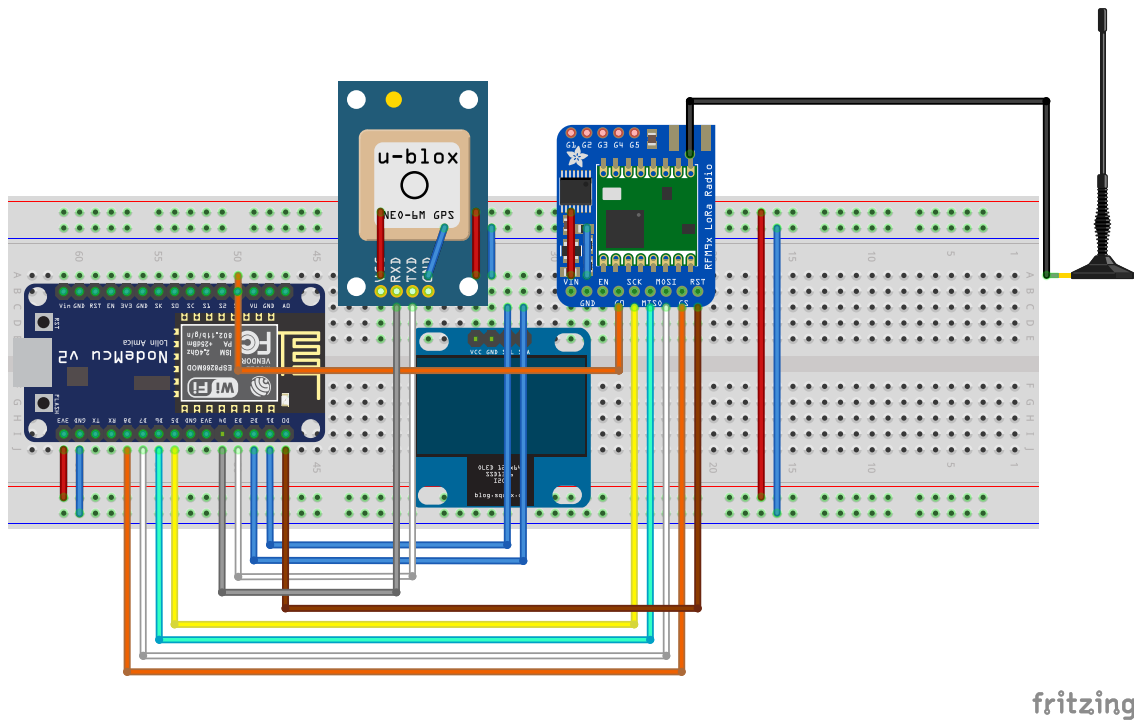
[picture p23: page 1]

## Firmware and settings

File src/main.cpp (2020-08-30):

#include <Arduino.h>

#ifdef WDT_ENABLE
  #ifdef ESP32
    #include <esp_task_wdt.h>

    // watchdog timeout: give it at least 30 seconds,
    // because some processes need some time (e.g. OTA)
    // alternative: feed the watchdog during OTA upload ;)
    #define WDT_TIMEOUT 10
  #endif
#endif

#include "config.hpp"

// include wifi functionality for asynchronous wifi handling
#include "function_wifi.hpp"

// include OTA functionality (ability for Over The Air updates)
#include "function_ota.hpp"

#include "function_oled.hpp"

#include "function_gps.hpp"

#include "function_mqtt.hpp"

#ifdef LORA_TOPO_P2P
  // #include "function_lora_rh.hpp"
  #include "function_lora_sm.hpp"
#elif LORA_TOPO_TTN
  #include "function_lorawan_ttn.hpp"
#endif

TinyGPSPlus g_s_gps_values;
struct_gps_RunningAVG_Median g_s_gps_avg;

bool g_b_wifi_connected = false;
bool g_b_iicOLED_connected = false;
// bool g_b_valid_gps_signal = false;
// unsigned long g_ul_delayTime = 2000; // ms

//variables for blinking an LED with Millis
// D3 = GPIO0 = external LED
// D4 = GPIO2 = internal Wifi LED
//int pin_led = BUILTIN_LED;
// const int g_i_led_pin = 2; // ESP8266 Pin to which onboard LED is connected
unsigned long g_ul_previousMillis = 0;  // will store last time LED was updated
const unsigned long g_ul_delayTime = 2000;  // interval at which to blink (milliseconds)
bool g_b_ledState = false;  // ledState used to set the LED

void setup() {
  Serial.begin(115200);
  // while (!Serial) {
  //   ; // wait for serial port to connect. Needed for native USB port only
  // }

// enable watchdog functionality
#ifdef WDT_ENABLE
  #ifdef ESP32
    // Initialize the Task Watchdog Timer (TWDT)
    // Enable panic so ESP32 restarts
    // Parameters:
    //   timeout: timeout period of TWDT in seconds
    //   panic: flag that controls whether the panic handler will be executed when the TWDT times out
    esp_task_wdt_init(WDT_TIMEOUT, true);

    // Subscribe current thread (handle=NULL) to TWDT for watching
    // Each subscribed task must periodically call esp_task_wdt_reset() to prevent the TWDT from elapsing its timeout period.
    esp_task_wdt_add(NULL);
  #elif ESP8266
    ESP.wdtEnable(0); // how to set the desired timeout??
    // disable the software watchdog (hardware watchdog will bite after timeout of about 8 s ...)
    // the hardware watchdog will still remain active, causing a reset after some time
    ESP.wdtDisable();
  #endif
#endif

  initSS_gps();

  // pinMode(g_i_led_pin, OUTPUT);

  function_wifi_setup();

  function_mqtt_setup(); // setup MQTT functionality

  function_wifi_connect();

  function_mqtt_connect_PubTasks();

  g_b_iicOLED_connected = connectOLEDiic();

#ifdef LORA_TOPO_P2P
  function_lora_setup();
#elif LORA_TOPO_TTN
  function_lorawan_ttn_setup();
#endif
}

void loop() {
// feed the watchdog so that hopefully it doesn't bite you
#ifdef WDT_ENABLE
  #ifdef ESP32
    // reset the TWDT on behalf of the currently running task
    esp_task_wdt_reset();
  #elif ESP8266
    ESP.wdtFeed();
  #endif
#endif

  if (get_wifi_isConnected()) {
    function_ota_handle();  // call handler function for OTA
  }

#ifdef LORA_TOPO_P2P
  function_lora_send_handler();
#elif LORA_TOPO_TTN
  function_lorawan_ttn_send_handler();
#endif

  g_s_gps_values = read_gps();

  // loop main task without delay
  unsigned long currentMillis = millis();
  if (currentMillis - g_ul_previousMillis >= g_ul_delayTime) {
    // save the last time the main task was called
    g_ul_previousMillis = currentMillis;
    // if the LED is off turn it on and vice-versa:
    g_b_ledState = not(g_b_ledState);
    // set the LED with the ledState of the variable:
    // digitalWrite(g_i_led_pin,  g_b_ledState);

    // updating the oled display non-blocking with Ticker does produce hard panic errors (esp8266 crashes)
    if (g_b_iicOLED_connected) {
      printOLED_begin();
      printOLED_values_str(0, "Host: ", get_wifi_hostname());

#if defined(LORA_OLED_P2P) && defined(LORA_TOPO_P2P)
      String l_str_msgIDs = "MsgID: " + String(function_lora_get_msgID()) + ", int: " + String(function_lora_get_msgCount());
      printOLED_str(10, l_str_msgIDs);
      String l_str_rssi_snr = "RSSI: " + String(function_lora_get_rssi()) + ", SNR: " + String(function_lora_get_snr());
      printOLED_str(20, l_str_rssi_snr);
#else
      printOLED_values_str(10, "IP: ", get_wifi_IP_str());
      printOLED_values_flt(20, "RSSI: ", get_wifi_RSSI(), 2, 0, " dBm");
#endif

#ifdef LORA_TOPO_P2P
      function_lora_serial_out();
#endif

      Serial.printf("[WIFI] Hostname: %s\r\n", get_wifi_hostname().c_str());
      Serial.printf("[WIFI] IP      : %s\r\n", get_wifi_IP_str().c_str());
      Serial.printf("[WIFI] RSSI    : %d dBm\r\n", get_wifi_RSSI());

      mqtt_set_wifi_rssi_dBm(get_wifi_RSSI());

      if (g_s_gps_values.location.isValid()) {
        // smoothing GPS positions: calculate running (floating) average and median
        gps_RunningAVG_Median_addValues();
        g_s_gps_avg = get_gps_RunningAVG_Median();

        // Serial.println("### GPS Start ###");
        Serial.printf("[GPS] Latitude  : %.9f* N\r\n", g_s_gps_values.location.lat());
        Serial.printf("[GPS] Longitude : %.9f* E\r\n", g_s_gps_values.location.lng());
        Serial.printf("[GPS] Lat (AVG) : %.9f* N\r\n", g_s_gps_avg.gps_RunningAVG_lat);
        Serial.printf("[GPS] Lng (AVG) : %.9f* E\r\n", g_s_gps_avg.gps_RunningAVG_lng);
        Serial.printf("[GPS] Elevation : %f m\r\n", g_s_gps_avg.gps_RunningAVG_alt);

        // Serial.printf("Lat (AVG) Buffer size: %d, Buffer count: %d\r\n", g_s_gps_avg.gps_RunningAVG_lat_size, g_s_gps_avg.gps_RunningAVG_lat_cnt);
        // Serial.printf("Lng (AVG) Buffer size: %d, Buffer count: %d\r\n", g_s_gps_avg.gps_RunningAVG_lng_size, g_s_gps_avg.gps_RunningAVG_lng_cnt);
        // Serial.printf("Alt (AVG) Buffer size: %d, Buffer count: %d\r\n", g_s_gps_avg.gps_RunningAVG_alt_size, g_s_gps_avg.gps_RunningAVG_alt_cnt);

        Serial.printf("[GPS] Satellites: %d\r\n", g_s_gps_values.satellites.value());
        Serial.printf("[GPS] Time Raw  : %d\r\n", g_s_gps_values.time.value()); // raw time
        Serial.printf("[GPS] Time UTC  : %d:%d:%d\r\n", g_s_gps_values.time.hour(), g_s_gps_values.time.minute(), g_s_gps_values.time.second()); // GPS time UTC
        Serial.printf("[GPS] Heading   : %.2f*\r\n", g_s_gps_values.course.deg());
        Serial.printf("[GPS] Speed     : %.2f km/h\r\n", g_s_gps_values.speed.kmph());
        // Serial.println("### GPS End ###");

        printOLED_values_flt(30, "Lat.: ", g_s_gps_values.location.lat(), 12, 9, "° N");
        printOLED_values_flt(40, "Lng.: ", g_s_gps_values.location.lng(), 12, 9, "° E");
        printOLED_values_flt(50, "Sat.: ", g_s_gps_values.satellites.value(), 2, 0, "");
        printOLED_end();

        String l_str_time = String(g_s_gps_values.date.year()) + "-"
                          + String(g_s_gps_values.date.month()) + "-"
                          + String(g_s_gps_values.date.day()) + " "
                          + String(g_s_gps_values.time.hour()) + ":"
                          + String(g_s_gps_values.time.minute())  + ":"
                          + String(g_s_gps_values.time.second());

        mqtt_set_gps_valid(true);

        mqtt_set_gps_json(MQTT_SENSOR_NODE, l_str_time, "mobile bug", "fa-bug", GPS_COLOR,
                          g_s_gps_values.satellites.value(),
                          g_s_gps_values.altitude.meters(),
                          get_wifi_RSSI(),
                          g_s_gps_values.location.lat(),
                          g_s_gps_values.location.lng(),
                          g_s_gps_avg.gps_RunningAVG_lat,
                          g_s_gps_avg.gps_RunningAVG_lng,
                          g_s_gps_avg.gps_RunningAVG_alt,
                          g_s_gps_avg.gps_RunningMedian_lat,
                          g_s_gps_avg.gps_RunningMedian_lng,
                          g_s_gps_avg.gps_RunningMedian_alt);

#if LORA_TOPO_TTN
        function_lorawan_ttn_send_gps(g_s_gps_avg.gps_RunningAVG_lat, g_s_gps_avg.gps_RunningAVG_lng);
#endif
      }
      else {
        Serial.println("#### No GPS Signal .. ####");
        mqtt_set_gps_valid(false);

        printOLED_str(30, "# No GPS Signal .. #");
        printOLED_str(40, "");
        printOLED_str(50, "");
        printOLED_end();
      }
    }
  }
}






//

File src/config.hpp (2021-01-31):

#ifndef config_hpp
#define config_hpp

// Include your own wifi credentials here ...
// ... 'WIFI_SSID' and 'WIFI_PASSWORD' has to be defined there by yourself.
#include "wifi_creds.hpp"

// choose hostname and sensors (done by build_flags in platformio.ini)
#ifdef WEMOS_D1_MINI_PRO
  #define HOSTNAME "Wemos_D1_mini_pro"
  #define BOX_HAS_CCS811  // CO2 sensor
  // #define BOX 'esp8266_d1_box'
  #define OLED_1_3_IN
#elif NODE_MCU_LORA_1
  #define HOSTNAME "LoRaNode_1"
  // #define BOX_HAS_PIR     // PIR motion sensor
  // #define BOX_HAS_CCS811  // CO2 sensor
  // #define BOX 'esp8266_node_mcu_lora_1'
  #define OLED_1_3_IN
#elif NODE_MCU_LORA_2
  #define HOSTNAME "LoRaNode_2"
  // #define BOX_HAS_PIR     // PIR motion sensor
  // #define BOX_HAS_CCS811  // CO2 sensor
  // #define BOX 'esp8266_node_mcu_lora_2'
  #define OLED_1_3_IN
#elif NODE_MCU_LORA_2_ESP32
  #define HOSTNAME "LoRaNode_2_ESP32"
  // DTH11 temperature and humidity sensor
  // #define BOX_HAS_DTH11
  // SHT35 temperature and humidity sensor
  #define BOX_HAS_SHT35

  // #define BOX_HAS_PIR     // PIR motion sensor
  // #define BOX_HAS_CCS811  // CO2 sensor
  // #define BOX 'esp32_node_mcu_lora_2'
  // #define OLED_1_3_IN
#elif DEAUTHER_OLED
  #define HOSTNAME "Deauther_oled"
  // #define BOX 'esp8266_deauther_oled'
#endif

// choose mqtt broker (done by build_flags in platformio.ini)
#ifdef MQTT_RASPI_TOUCH
  //#define MQTT_HOST IPAddress(192, 168, 60, 190)
  #define MQTT_HOST "RaspiB3PiTouch7"
  #define MQTT_PORT 1883
#elif MQTT_RASPI_EPAPER
  #define MQTT_HOST "RaspiB3plus_ePaper"
  #define MQTT_PORT 1883
#elif MQTT_RASPI_LORAGW
  #define MQTT_HOST "RaspiB3plusLoRaGateway"
  #define MQTT_PORT 1883
#endif

// define mqtt root topics
#ifdef WEMOS_D1_MINI_PRO
  #define MQTT_ROOT_TOPIC "d1_box"
#elif NODE_MCU_LORA_1
  #define MQTT_ROOT_TOPIC "lora_1"
  #define MQTT_SENSOR_NODE "lora_1_gps"
  #define GPS_COLOR "Yellow"
#elif NODE_MCU_LORA_2
  #define MQTT_ROOT_TOPIC "lora_2"
  #define MQTT_SENSOR_NODE "lora_2_gps"
  #define GPS_COLOR "Blue"
#elif NODE_MCU_LORA_2_ESP32
  #define MQTT_ROOT_TOPIC "lora_2_esp32"
  #define MQTT_SENSOR_NODE "lora_2_gps_esp32"
  #define GPS_COLOR "Blue"
#elif NODE_MCU_V2
  #define MQTT_ROOT_TOPIC "node_mcu"
#elif DEAUTHER_OLED
  #define MQTT_ROOT_TOPIC "deauther_oled"
#endif

// LoRa topology: decide between Peer-to-Peer sending between 2 LoRa nodes
// and sending in an LoRaWAN network using a LoRaWAN gateway and The Things Network (TTN)
#ifdef LORA_TOPO_P2P
  #warning "Chosen topology for LoRa is Peer-to-Peer"
  #define LORA_OLED_P2P

  // define LoRa sender or receiver role
  #ifdef NODE_MCU_LORA_1
    #define LORA_SENDER
  #elif defined(NODE_MCU_LORA_2) || defined(NODE_MCU_LORA_2_ESP32)
    #define LORA_RECEIVER
  #endif
#elif LORA_TOPO_TTN
  #warning "Chosen topology for LoRa is LoRaWAN and TTN"
  #define LORA_OLED_TTN
#else
  #warning "You didn't choose a LoRa or LoRaWAN topology!"
#endif








#endif // config_hpp

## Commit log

2019-10-13 added led blink for testing
2019-10-15 added software serial functionality for reading the GPS device
2019-10-15 activated the GPS functionality (does not work properly at the moment)
    [main.cpp]
2019-10-16 adapted printOLED_str() to printOLED_values()
2019-10-16 err: print to OLED
2019-10-19 added mqtt rough structure (not working yet)
    [function_mqtt.cpp]
2019-10-20 print to OLED: configurable precision for displaying floats/doubles
2019-10-22 fix: mqtt reconnect timer was calling the wrong function, so after wifi signal losses esp8266 didn't reconnect to mqtt server
    [function_mqtt.cpp, main.cpp]
2019-11-16 added fritzing schematic of complete application
    [NodeMcu_LoRa_GPS_OLED.fzz]
2019-11-22 adapt softwareserial pins to new wiring layout to comply with lora transceiver
2019-12-01 fritzing schematic edited (pinout gps module)
    [NodeMcu_LoRa_GPS_OLED.fzz]
2019-12-08 readme: images of test boards included
2019-12-08 images: removed gps from exif
    [NodeMcu_LoRa_GPS_OLED.fzz]
2019-12-08 fritzing schematics tidied up
    [NodeMcu_LoRa_GPS_OLED.fzz]
2019-12-15 [bugfix] external interrupts conflict with wifi connection attempts and ota updates and lead to sporadic crashes! => solution (workaround): disable external interrupts temporarily
    [function_ota.cpp, function_wifi.cpp]
2020-01-05 - include my own local copy of RunningAverage library - it is rewritten to revert back from float to double - for smoothing GPS values I need much higher precision than float with 4 bytes - in compar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
2020-01-06 - include my own local copy of RunningMedian library - it is rewritten to revert back from float to double - for smoothing GPS values I need much higher precision than float with 4 bytes - in compari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
    [function_gps.cpp]
2020-04-07 - prepare for migration to ESP32 - smoothing GPS coordinates with floating averages and floating medians
    [NodeMcu32s_LoRa_GPS_OLED.fzz, NodeMcu_LoRa_GPS_OLED.fzz]
2020-04-07 Node-RED Flow described
2020-04-07 inserted screenshot of SQLite database layout
2020-04-07 - smoothed altitude values with floating averages and floating medians - inserted smoothed and raw values in JsonObject (rebuild structure) - adapted Node-RED Flow to take average altitude values and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
2020-04-07 resorted the BOM (bill of materials)
2020-04-30 new screenshot of expanded Node-RED Flow
2020-04-30 updated link to Node-RED Flow
2020-04-30 migration to ESP32 (necessary for LoRaWAN and TTN) + revised OTA functionality
2020-04-30 inserted table of contents (manually created ...)
2020-05-08 fixed wifi reconnecting problems
    [function_wifi.cpp]
2020-06-06 fixed functionality for the correct initialization of the GPS average arrays
    [function_gps.cpp]
2020-06-06 switch between 2 different displays via defines
2020-06-06 improved WiFi connect, disconnect and reconnect handling to avoid system freezes and hard reboots by conflicting external interrupts
    [function_wifi.cpp]
2020-06-06 changed user defined compile error to warning
    [config.hpp]
2020-06-06 some function names changed; fixed an error with GPS average handling
    [main.cpp]
2020-06-06 expanded Tx functionality to send GPS coordinates and improved proper interrupt handling
2020-06-06 fixed OLED display errors by inserting 2 10k pull-up resistors in I2C data and clock lines; included DHT11 sensor (temperature and humidity) and an external LED
    [NodeMcu32s_LoRa_GPS_OLED.fzz]
2020-06-06 inserted images showing OLED display errors with / without 2 10k pull-up resistors in I2C data and clock lines
2020-06-06 edited Node-RED flow
2020-06-06 new Node-RED flow for LoRaWAN TTN
2020-06-09 improved the serial output + bug fixes in interrupt handling
    [function_wifi.cpp]
2020-06-09 bug fixes in interrupt handling
    [function_gps.cpp, function_lorawan_ttn.cpp, function_ota.cpp]
2020-06-11 bug fixes in interrupt handling: GPS is activated when MQTT connection is finished
    [function_lorawan_ttn.cpp, function_mqtt.cpp, function_wifi.cpp]
2020-06-14 bux fixes for reactivating LoRa transmissions + generate uptime counter and transmit via LoRa
    [function_lorawan_ttn.cpp, function_lorawan_ttn.hpp]
2020-06-14 updated Node-RED flow to write esp_uptime to SQLite database
2020-08-29 added watchdog functionality for automatically restarting the node after crashes (guru meditation errors)
    [main.cpp]
2020-08-30 added functionality to feed the watchdog during OTA uploads, that it will not interrupt it anymore
2020-11-18 added library dependency 'adafruit/Adafruit Unified Sensor'
2020-11-28 added functionality for reading an outdoor resistant SHT35 sensor (temperature and humidity)
2021-01-27 included SHT35 sensor
2021-01-31 expanded decimals to 2 for the temperature value of the new SHT35 sensor because of its better resolution
2021-04-12 decreased filter size of floating average and floating median (due to observed much to 'round' curves in gps tracks)
